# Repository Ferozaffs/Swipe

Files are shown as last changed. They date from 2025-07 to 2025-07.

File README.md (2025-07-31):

# Swipe
## Summary
A macro tool that is using some custom hardware, also works with keyboard.
Btw the name Swipe comes from the movements when using the band to activate functions.



## Gesture
Through the "Band" invoke different functions through gestures. Using dynamic time warping to match the different acceleration curves.

Hardware is based on the very small [CodeCell](https://microbots.io/products/codecell?variant=49714638717261)

DTW implementation made by https://github.com/kkartavenka/FastDtw.CSharp

## Macro pad
The macro pad is a bluetooth numpad based on the [DumbPad](https://github.com/imchipwood/dumbpad) platform. Changes have been made to enable hot-swappable keys an ESP32 controller.

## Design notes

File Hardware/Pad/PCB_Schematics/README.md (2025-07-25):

# dumbpad - ESP32 mod

Original designed by [deveth0](https://www.github.com/deveth0).

## Description

Modified version to fit ESP32 dev kit, removal of RGB

## Acknowledgements

Some of the footprints are extracted from the awesome [Corne Keyboard](https://github.com/foostan/crkbd) by [Kosuke Adachi](https://github.com/foostan).

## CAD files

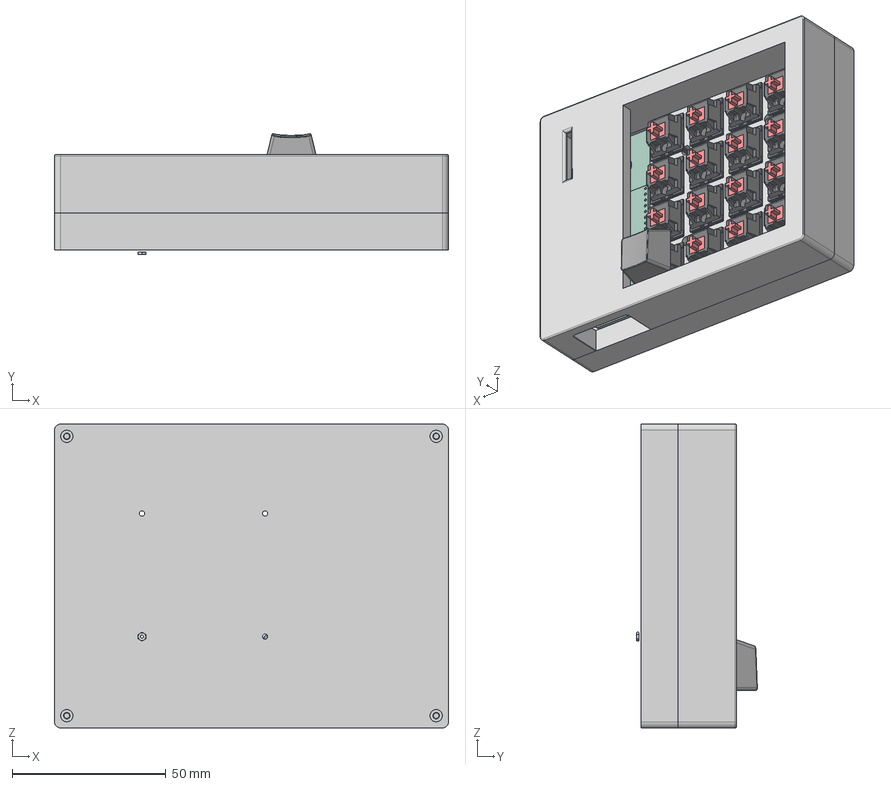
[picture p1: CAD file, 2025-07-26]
Hardware/Pad/CAD/Pad.step
128.0 x 39.2 x 98.7 mm
dumbpad_PCB
90591A311_NO THREADS_Zinc-Plated Steel Hex Nut
ESP32-DevKit-Lipo_Rev_A1_PCB
1x1 R4 v6

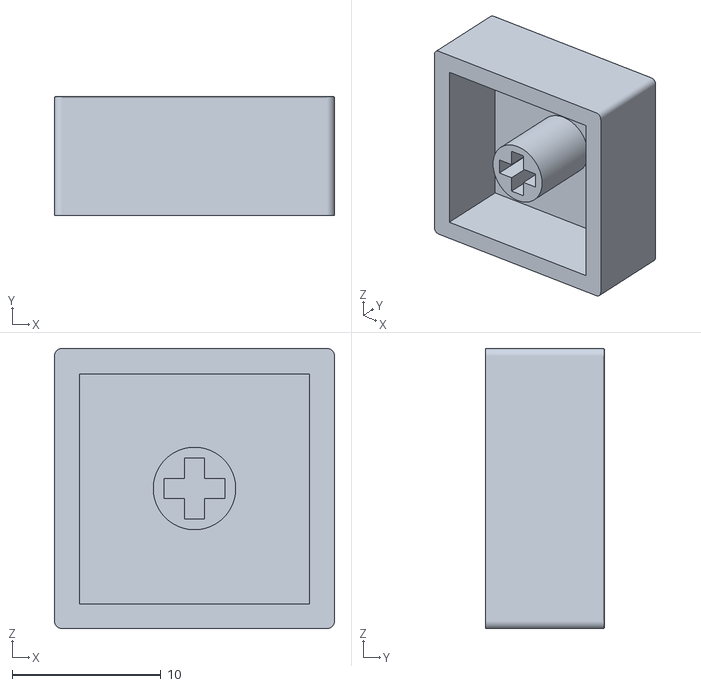
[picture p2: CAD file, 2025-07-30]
Hardware/Pad/CAD/PrintReady/FlatKey.stl
18.8 x 8.00 x 18.8

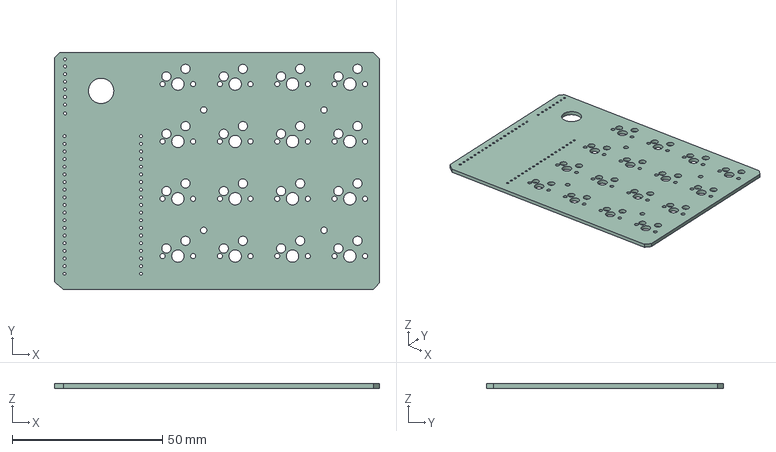
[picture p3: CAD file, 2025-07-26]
Hardware/Pad/PCB_Schematics/dumbpad.step
108.0 x 78.7 x 1.51 mm

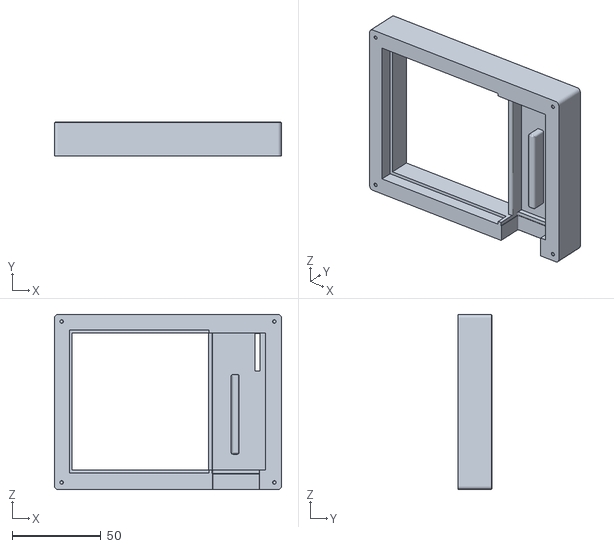
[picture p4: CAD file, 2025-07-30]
Hardware/Pad/CAD/PrintReady/Top.stl
128.0 x 19.0 x 98.7

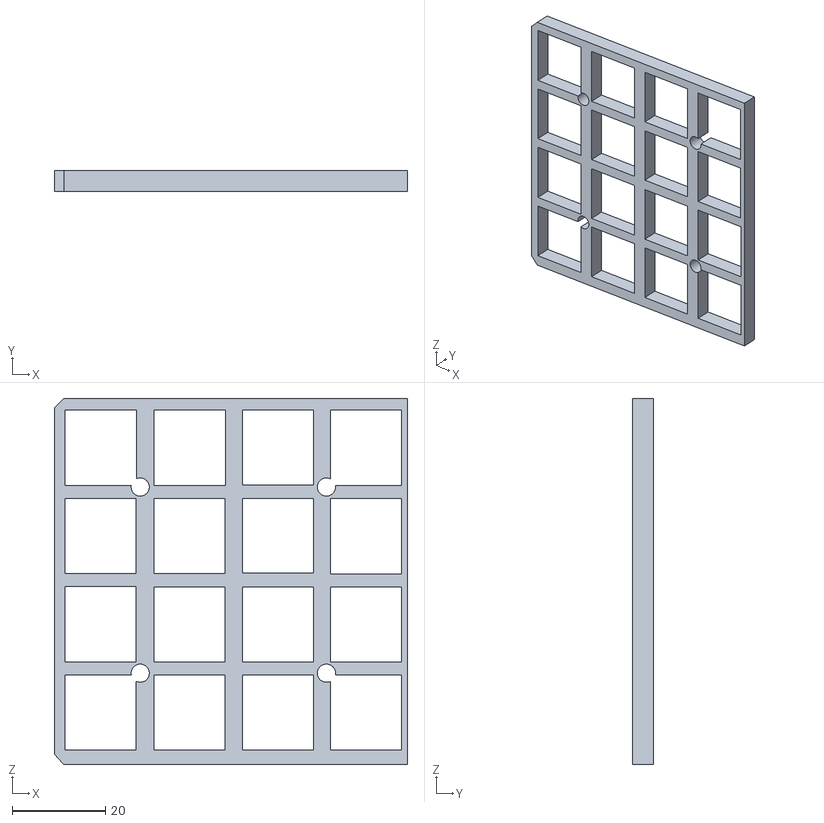
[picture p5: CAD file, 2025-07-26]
Hardware/Pad/CAD/PrintReady/Plate.stl
75.9 x 4.50 x 78.7

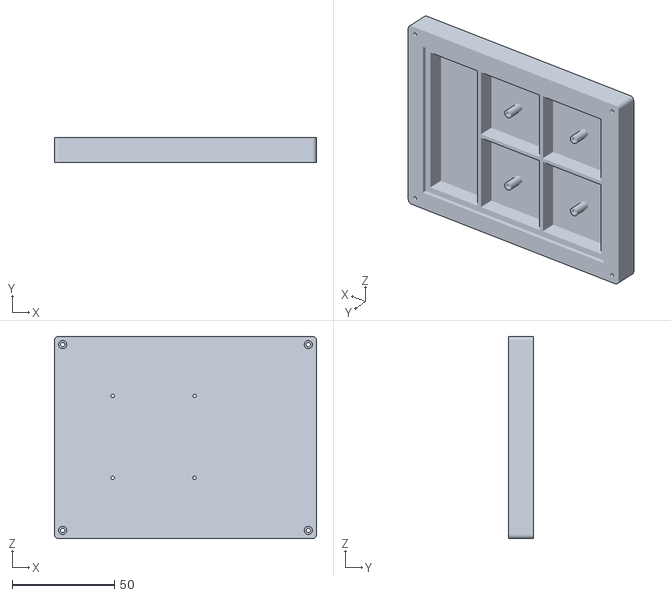
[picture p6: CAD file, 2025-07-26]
Hardware/Pad/CAD/PrintReady/Bottom.stl
128.0 x 12.0 x 98.7

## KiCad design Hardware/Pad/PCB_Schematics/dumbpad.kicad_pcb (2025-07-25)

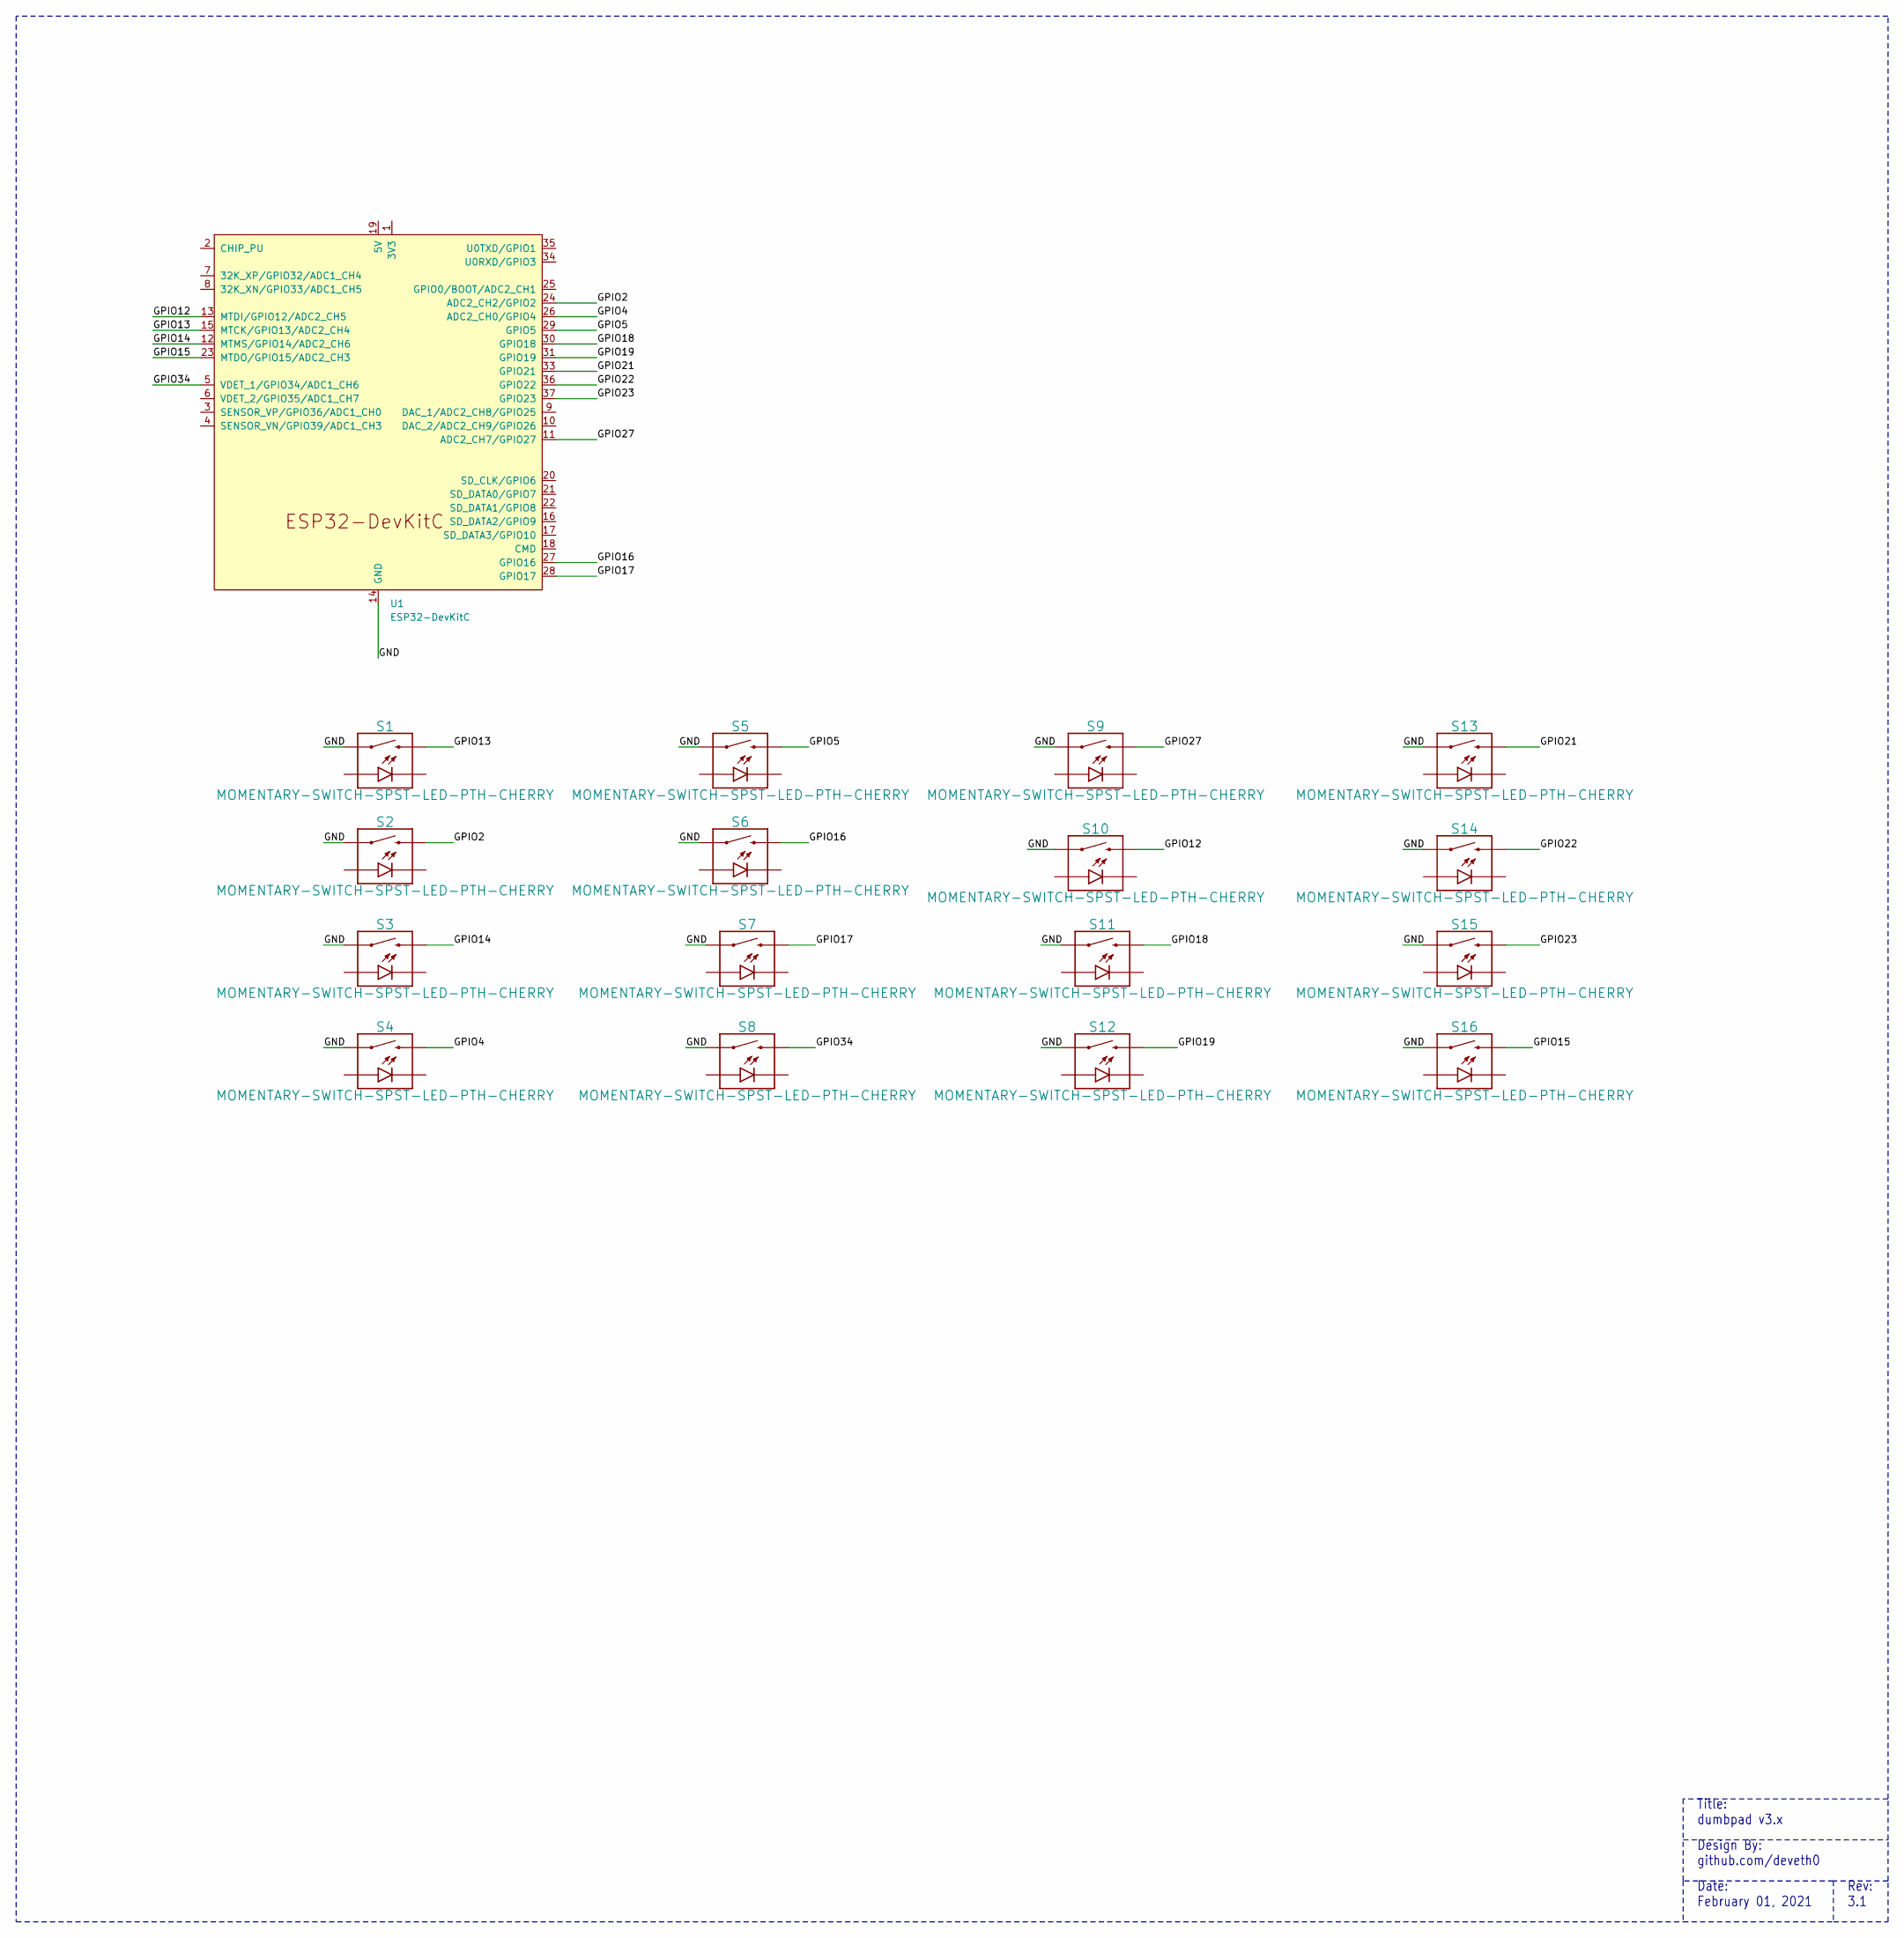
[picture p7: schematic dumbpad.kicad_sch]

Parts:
S1, S2, S3, S4, S5, S6, S7, S8, S9, S10, S11, S12, S13, S14, S15, S16: MOMENTARY-SWITCH-SPST-LED-PTH-CHERRY; Kailh-CPG151101S11_MX_Socket-1.00u
U1: ESP32-DevKitC

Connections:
/GND: S1.S1 (1), S2.S1 (1), S3.S1 (1), S4.S1 (1), S5.S1 (1), S6.S1 (1), S7.S1 (1), S8.S1 (1), S9.S1 (1), S10.S1 (1), S11.S1 (1), S12.S1 (1), S13.S1 (1), S14.S1 (1), S15.S1 (1), S16.S1 (1), U1.14 (GND), U1.32 (GND), U1.38 (GND); also elsewhere on the board
/GPIO2: S2.S2 (2), U1.24 (ADC2_CH2/GPIO2); also elsewhere on the board
/GPIO4: S4.S2 (2), U1.26 (ADC2_CH0/GPIO4); also elsewhere on the board
/GPIO5: S5.S2 (2), U1.29 (GPIO5); also elsewhere on the board
/GPIO12: S10.S2 (2), U1.13 (MTDI/GPIO12/ADC2_CH5); also elsewhere on the board
/GPIO13: S1.S2 (2), U1.15 (MTCK/GPIO13/ADC2_CH4); also elsewhere on the board
/GPIO14: S3.S2 (2), U1.12 (MTMS/GPIO14/ADC2_CH6); also elsewhere on the board
/GPIO15: S16.S2 (2), U1.23 (MTDO/GPIO15/ADC2_CH3); also elsewhere on the board
/GPIO16: S6.S2 (2), U1.27 (GPIO16); also elsewhere on the board
/GPIO17: S7.S2 (2), U1.28 (GPIO17); also elsewhere on the board
/GPIO18: S11.S2 (2), U1.30 (GPIO18); also elsewhere on the board
/GPIO19: S12.S2 (2), U1.31 (GPIO19); also elsewhere on the board
/GPIO21: S13.S2 (2), U1.33 (GPIO21); also elsewhere on the board
/GPIO22: S14.S2 (2), U1.36 (GPIO22); also elsewhere on the board
/GPIO23: S15.S2 (2), U1.37 (GPIO23); also elsewhere on the board
/GPIO27: S9.S2 (2), U1.11 (ADC2_CH7/GPIO27); also elsewhere on the board
/GPIO34: S8.S2 (2), U1.5 (VDET_1/GPIO34/ADC1_CH6); also elsewhere on the board

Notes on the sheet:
Rev: 3.1
Design By: github.com/deveth0
Title: dumbpad v3.x
Date: February 01, 2021

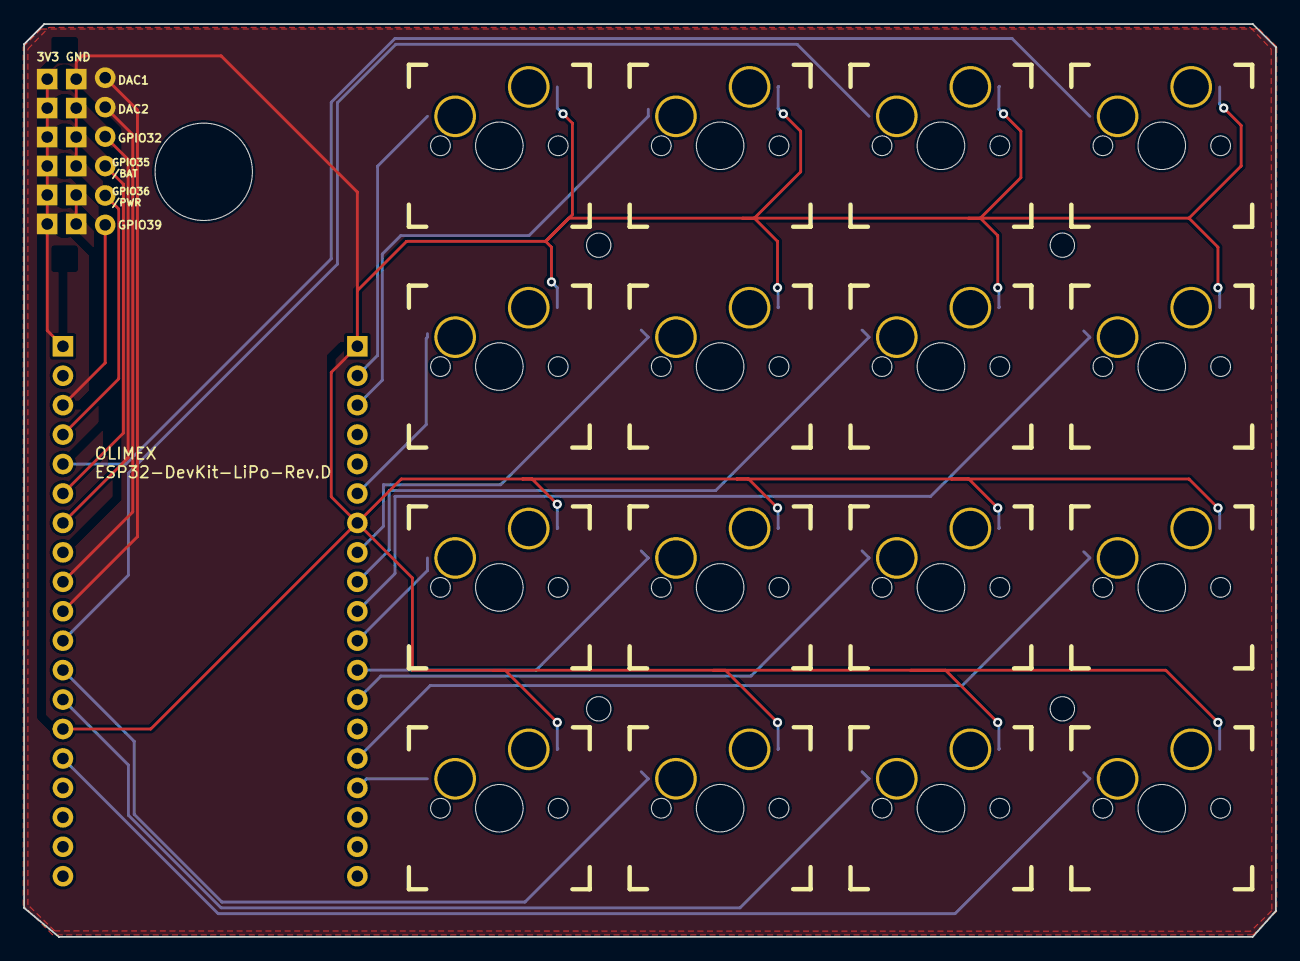
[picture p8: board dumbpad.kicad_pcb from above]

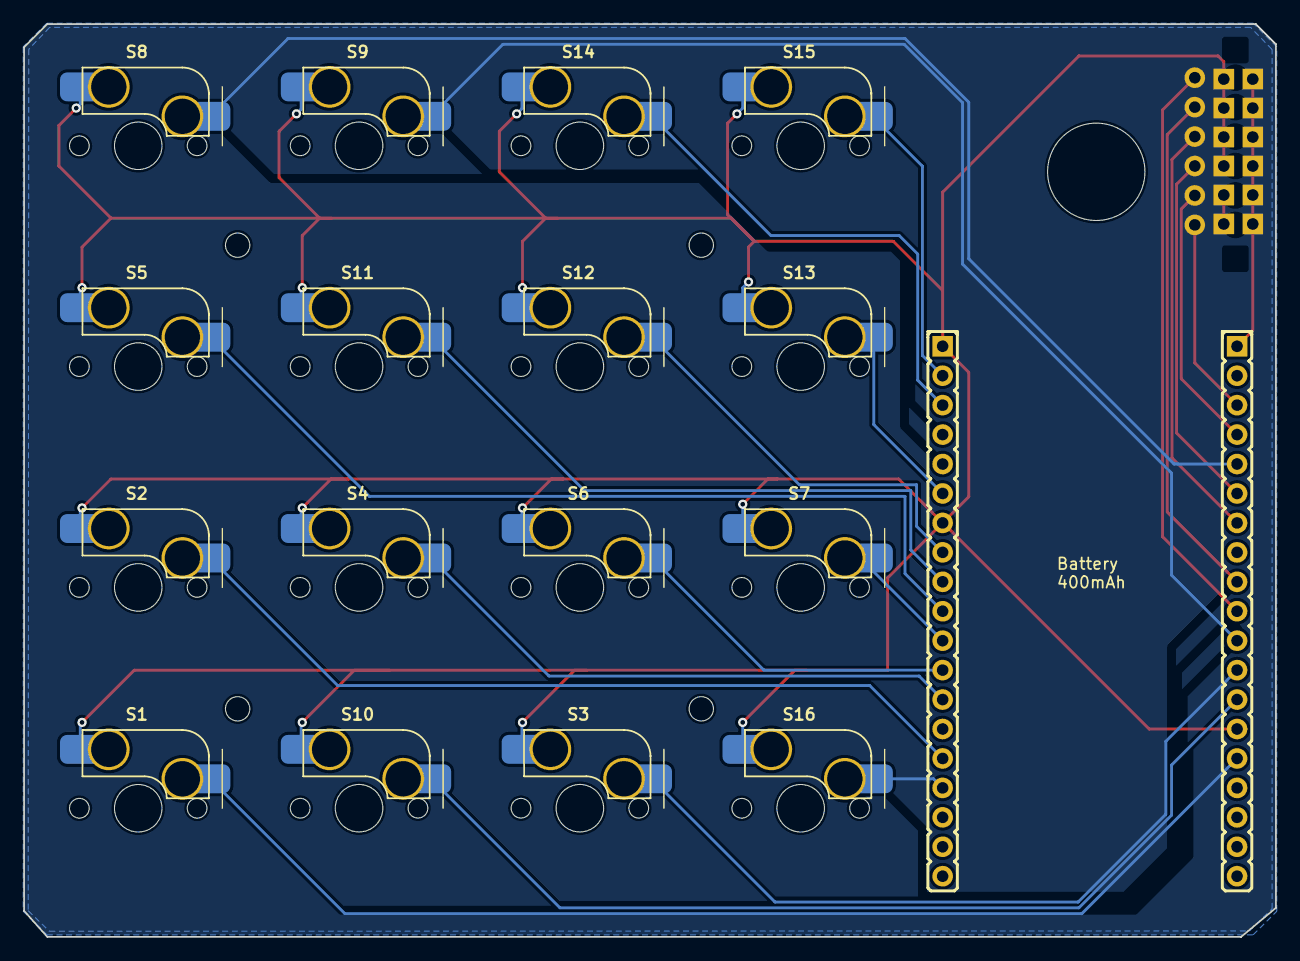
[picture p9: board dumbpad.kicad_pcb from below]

Board: 2 copper layers, 108.0 x 78.7 mm, 18 parts (18 on the bottom side), 17 nets.

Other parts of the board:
EXT1, EXT2: HN1x19

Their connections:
/GND: EXT1.14, EXT2.1, EXT2.7; also elsewhere on the board
/GPIO2: EXT2.15; also elsewhere on the board
/GPIO4: EXT2.13; also elsewhere on the board
/GPIO5: EXT2.10; also elsewhere on the board
/GPIO12: EXT1.13; also elsewhere on the board
/GPIO13: EXT1.15; also elsewhere on the board
/GPIO14: EXT1.12; also elsewhere on the board
/GPIO15: EXT2.16; also elsewhere on the board
/GPIO16: EXT2.12; also elsewhere on the board
/GPIO17: EXT2.11; also elsewhere on the board
/GPIO18: EXT2.9; also elsewhere on the board
/GPIO19: EXT2.8; also elsewhere on the board
/GPIO21: EXT2.6; also elsewhere on the board
/GPIO22: EXT2.3; also elsewhere on the board
/GPIO23: EXT2.2; also elsewhere on the board
/GPIO27: EXT1.11; also elsewhere on the board
/GPIO34: EXT1.5; also elsewhere on the board

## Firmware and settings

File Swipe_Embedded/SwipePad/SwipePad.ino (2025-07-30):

#include <ArduinoBLE.h>

BLEService bleService("f9c97383-3025-4a1f-9903-8b313565184e");
BLEStringCharacteristic bleCharacteristic("67391cf3-acc4-4a8c-af95-0131221895f2", BLERead | BLENotify, 96);

int inputPins[] = {
  3, 1, 22, 23,
  5, 18, 19, 21,
  2, 4, 16, 17,
  12, 27, 26, 25
};

bool hasInput = false;
unsigned long lastActivityTime = millis();
const unsigned long idleTimeout = 15 * 60 * 1000;

const unsigned long pulseDuration = 100; 
const unsigned long pulseInterval = 30000;   
unsigned long previousMillis = 0;
bool ledOn = false;

const int ledStatusPin = 32;

void setupPins() {
  Serial.println("Setting pins");

  for (int i = 0; i < sizeof(inputPins) / sizeof(inputPins[0]); i++) 
  {
    pinMode(inputPins[i], INPUT_PULLUP);
  }
}

String getPinState() {
  String state = "State: ";

  hasInput = false;
  for (int i = 0; i < sizeof(inputPins) / sizeof(inputPins[0]); i++) 
  {
    if(i != 0) {
      state += ",";
    }
    int value = 1 - digitalRead(inputPins[i]);
    if(value > 0) {
      hasInput = true;
    }
    state += value;
  }

  return state;
}

void enterDeepSleep() {
  uint64_t pinMask = 0;
  for (int i = 0; i < sizeof(inputPins) / sizeof(inputPins[0]); i++) {
    pinMask |= 1ULL << inputPins[i];
  }

  digitalWrite(ledStatusPin, LOW);
  esp_sleep_enable_ext0_wakeup(GPIO_NUM_25, LOW);
  esp_deep_sleep_start();
}

void updateStatusLED(unsigned long millis) {
  if (!ledOn && millis - previousMillis >= pulseInterval) {
    digitalWrite(ledStatusPin, HIGH);
    ledOn = true;
    previousMillis = millis;
  } else if (ledOn && millis - previousMillis >= pulseDuration) {
    digitalWrite(ledStatusPin, LOW);
    ledOn = false;
    previousMillis = millis;
  }
}

void updateStatus() {
  unsigned long currentMillis = millis();
  if (hasInput) {
    lastActivityTime = currentMillis;
    ledOn = false;
    previousMillis = 0;
  }
  updateStatusLED(currentMillis);

  if (currentMillis - lastActivityTime > idleTimeout) {
    enterDeepSleep();
  }
}

void setup() {  
  Serial.begin(115200);

  setupPins();

  if (!BLE.begin()) {
    Serial.println("BT: failed to initialize BLE!");
  }

  BLE.setLocalName("Swipe Pad v.1.0");
  BLE.setAdvertisedService(bleService);
  bleService.addCharacteristic(bleCharacteristic);
  BLE.addService(bleService);
  bleCharacteristic.writeValue(getPinState());

  BLE.advertise();

  Serial.println("BT: advertising");

  pinMode(ledStatusPin, OUTPUT);
}

void loop() {
    BLEDevice central = BLE.central();
    if (central) {
      Serial.println("BT: connected to central: ");
      Serial.println(central.address());

      while (central.connected()) {
          bleCharacteristic.writeValue(getPinState());         
          updateStatus();
          delay(10);
      }

      Serial.println("BT: disconnected from central: ");
      Serial.println(central.address()); 
    }
    else {
      Serial.println(getPinState());
      updateStatus();

      delay(10);
    }
}

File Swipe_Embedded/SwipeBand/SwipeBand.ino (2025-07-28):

#define DEBUG

#ifdef DEBUG
  #define DEBUG_PRINT(x) Serial.print(x)
  #define DEBUG_PRINTLN(x) Serial.println(x)
#else
  #define DEBUG_PRINT(x)
  #define DEBUG_PRINTLN(x)
#endif

#include <CodeCell.h>
#include <ArduinoBLE.h>

CodeCell cell;

BLEService bleService("13de80c4-cdd2-496e-901d-6537ea44f3d8");
BLEStringCharacteristic bleCharacteristic("b6fe5a0e-ff8d-494a-8885-143cda0100ea", BLERead | BLENotify, 96);

void setup() {
#ifdef DEBUG
    Serial.begin(115200);
#endif


  cell.Init(MOTION_LINEAR_ACC + LIGHT); 

  DEBUG_PRINTLN("Cell: started");

  if (!BLE.begin()) {
    DEBUG_PRINTLN("BT: failed to initialize BLE!");
    while (1) {
      cell.LED(1U, 0, 0);
    }
  }

  BLE.setLocalName("Swipe Band v.1.0");
  BLE.setAdvertisedService(bleService);
  bleService.addCharacteristic(bleCharacteristic);
  BLE.addService(bleService);
  bleCharacteristic.writeValue("0.0,0.0,0.0,0.0");

  BLE.advertise();

  DEBUG_PRINTLN("BT: advertising");
}

void loop() {
  if(cell.PowerStateRead() == 0)
  {
    unsigned long epochTime = millis() / 1000;

    BLEDevice central = BLE.central();
    if (central) {
      DEBUG_PRINT("BT: connected to central: ");
      DEBUG_PRINTLN(central.address());

      while (central.connected()) {
        epochTime = millis() / 1000;
        if(epochTime % 10 == 0) {
          cell.LED(0, 1U, 0);
        } 
        else if(epochTime % 10 == 2){
          cell.LED(0, 0, 0);
        }

        if (cell.Run(60)) {
          float x = 0.0;
          float y = 0.0;
          float z = 0.0;
          cell.Motion_LinearAccRead(x, y, z);
          float proximity = cell.Light_ProximityRead() * 0.002;
          
          String data = ">LinAccel_x:" + String(x) + "," + ">LinAccel_y:" + String(y) + "," + ">LinAccel_z:" + String(z) + "," + ">Proximity:" + proximity;
          bleCharacteristic.writeValue(data); 
        }
      }

      DEBUG_PRINT("BT: disconnected from central: ");
      DEBUG_PRINTLN(central.address()); 
    }

    cell.Run(1);
    if(epochTime % 10 == 0) {
      cell.LED(0, 1U, 1U);
    } 
    else if(epochTime % 10 == 2) { 
      cell.LED(0, 0, 0);
    }
  }
  else 
  {
    cell.Run(1);
  }
}

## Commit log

2025-03-26 Serialized test data, fixed threading issue
2025-05-27 fixed powershell launch
2025-07-02 added additional device to swipe ecosystem
    [dumbpad.kicad_pcb, dumbpad.kicad_sch]
2025-07-25 *Refactored functions and devices to prepare for swipe pad integration *Improved pcb design
    [dumbpad.kicad_pcb, dumbpad.kicad_sch]
2025-07-26 *Fixed integration of pad *Function loading bug fix *Fixed indices of embedded inputs and enabled button 1/2
    [SwipePad.ino]
2025-07-26 moved hardware files in repo
    [Bottom.stl, Plate.stl, Top.stl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]
2025-07-26 added .step files
    [Pad.step, dumbpad.step]
2025-07-28 *Added settings view *Renamed band device
2025-07-29 *Fixed deep sleep for pad device *Fixed auto reconnect from deep slepp *Added workflows for build and release
    [SwipePad.ino]
2025-07-30 *Updated ready to print stls
    [FlatKey.stl, Top.stl]
2025-07-31 *Updated release action in hope of preventing supply chain attack
